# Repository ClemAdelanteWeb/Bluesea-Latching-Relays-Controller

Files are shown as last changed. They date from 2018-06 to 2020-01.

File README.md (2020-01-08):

### dernier update 2020-01-08
Modification du comportement de la détection du voltage minimum de la batterie suite à un problème pendant 2 mois d'absence.
Le SOC était toujours à 100% parce que le Victron ne détectait pas les petites consommations de courant (Victron BMV lui-même, contrôleur de batterie, conso du régulateur de panneau solaire). Le relai de charge ne s'est dont pas fermé et à mon retour la batterie était à 10.7v

J'ai aussi rajouté des détections de voltage trop haut ou trop bas pour chaque cellule. Respectueusement 2.8v et 3.8v.

### Gestion des relais de charge et décharge dans un système de batterie Lifepo4.

Dans un système avec batteries au lifepo4, il faut pouvoir couper la charge quand les batteries sont pleines, pour ne pas passer en mode float et abimer les batteries sur le long terme.

Toute décharge doit être rendue impossible si les batteries ont atteint leur maximum de capacité de décharge (en général 80%), tout en laissant la charge se faire.
Il faut donc deux relais qui permettent de bloquer la charge, bloquer la décharge et bloquer les deux ce qui ferait l'équivalent d'un coupe circuit.

Il existe plusieurs sortent de relais. Les classiques à solenoide qui sont finalement constitués d'une lamelle à ressort que vient plaquer et fermer une bobine qui une fois alimentée crée un champ magnétique. Cette bobine c'est une solénoide, qu'on retrouve dans tous les relais classiques.

Il est aisé de déduire que ce type de relai consomme de l'énergie en permanence pour que le contact se fasse et le courant puisse passer. Pour les meilleurs d'entre eux 0.1A 24/24h ce qui fait un total de 2.4Ah par jour et comme il en faut 2 on arrive à une consommation de 4.8Ah par jour.

Un relai classique consomme entre 0.3 et 1A, on arrive dans ce cas à des consommations non négligeables de 14Ah à 48Ah par jour, simplement pour alimenter des relais qui servent à :
- Celui de charge (Charge) : couper les différentes charges et ne pas laisser la batterie Lifepo4 en mode float
- Celui de décharge (Load) : isoler de toute décharge profonde la batterie Lifepo4 tout en laissant la possibilité de la charger.

Les relais à solénoide optimisés (0.1A) sont très chers et même 5Ah par jour étaient de trop pour moi. 

Il existe aussi des relais mosfet qu'on trouve partout en électronique de puissance. S'il est plus compliquer d'estimer leur consommation lorsqu'ils sont passant, on comprend vite qu'elle est élevée puisqu'il faut un radiateur pour dissiper la chaleur qu'il produit.
Les mosfets sont aussi évincés de ma liste.

Heureusement il reste une solution : les relais bi-stable (ou latching relay en anglais).
Ceux-ci possèdent deux solénoides par relai. Un pour ouvrir le contact et un autre pour le fermer. Cette fois ci, et au contraire des relais classique, la position de la lamelle est permanente. C'est à dire qu'il n'y a pas besoin d'alimenter en permanence le solénoide pour créer un champ magnétique et forcer à lamelle à rester en place. Ici, comme pour un interrupteur à deux positions le relai ne consomme du courant que pour changer son état.

C'est parfait sauf que ça complique les choses puisqu'il y a deux bobines à alimenter par relai. Et comment savoir dans quelle position est le relai, ouvert ou fermé ?

J'ai choisi d'utiliser les relais Blue Sea ML-RBS qui ne consomment aucun courant et ont aussi une sortie qui permet de connaitre l'état du relai (ouvert ou fermé). On peut récupérer cette information et la traiter avec l'Arduino.

Il faut au moins 2A en 12v pour ouvrir ou fermer le relai. L'arduino seul n'est pas capable de fournir une tel intensité ni un telle tension. J'utilise donc une cascade de transisteurs.

Le soucis majeur lors de la création de la carte a été que les relais sont cablés en High Side, c'est à dire que les solenoides se trouvent du côté positif du circuit ce qui implique d'utiliser une cascade de transistor pour les activer avec un système PNP + NPN.

Pour déterminer le SOC (capacité restante dans la batterie en pourcentage) et l'utiliser pour gérer mes relais, j'utilise mon controleur de batterie Victron BMV702 qui fournit cette information par son port de communication (VE Direct). 

J'ai ensuite pris le parti d'acquérir les tensions des 4 cellules que composent la batteries pour controller les écarts entre les cellules, vérifier si l'une d'entre elles venait à être sous-chargée ou sur-chargée et connaitre la tension totale de la batterie.

Autant d'informations capitales qui permettent aussi de controller les relais sans les données fournies par le Victron, si celui-ci venait à tomber en panne.

J'ai aussi ajouté un bouton ON/OFF pour désactiver l'utilisation du SOC venant du Victron.

L'arduino reçoit donc les informations suivantes : 
- Etat du relai de charge
- Etat du relai de décharge
- SOC via le controleur Victron
- Tension de chaque cellule
- Utilisation du Victron ON / OFF

Par la suite, je vais créer un petit écran pour afficher toutes les données (voltage des cellules, état des relais, cycle de charge ou cycle de décharge, sur-tension ou sous-tension détectée). 

Pour des batteries au lithium, il n'est pas recommandé de maintenir la charge à 100% (mode float).
Aujourd'hui le programme ne possède qu'un cycle de charge qui va de 95 à 100% du SOC. Un cycle se compose comme ceci : la batterie se charge jusqu'à 100%, puis la charge est bloquée jusqu'à ce que la batterie se vide de 5%. A 95% de SOC, donc, la charge est de nouveau autorisée. 

Pour prolonger la durée de vie des batteries lithium, le SOC idéal est entre 50 et 70%. Ce serait intéressant de pouvoir faire des cycles entre 50 et 70% lorsque l'on est au port par exemple et qu'on n'a pas besoin de toute la capacité de la batterie puisqu'elle est rechargée au quai. 
Une autre utilisation de ce cycle 50-70% pourrait être faite en hivernage, période pendant laquelle la batterie n'est pas solicitée mais que la charge peut être faite par un panneau solaire par exemple. Grâce au controleur il serait possible de laisser tourner un petit ventilateur 12V dans les endroits qui en auraient besoin, par exemple, en aillant la certitude qu'il ne déchargera pas la batterie en dessous de 50%.

Une fois que l'autonomie totale est requise on retourne sur le cycle normal qui est de 95 à 100%.

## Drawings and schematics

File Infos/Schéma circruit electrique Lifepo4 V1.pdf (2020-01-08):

@

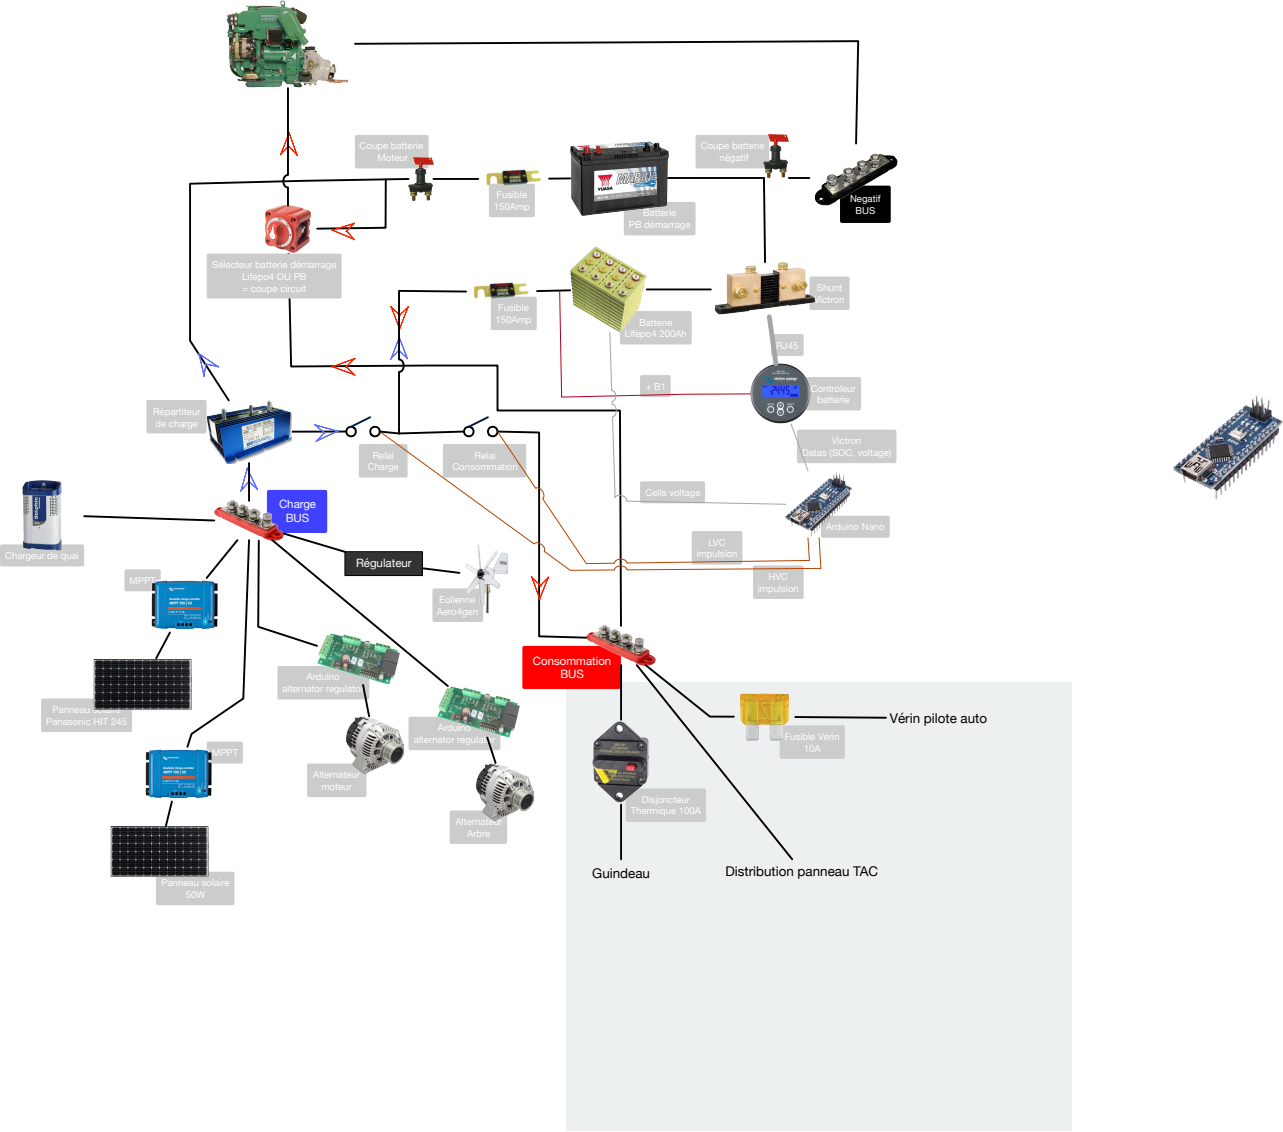
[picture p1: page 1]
Fusible Vérin 10A; Disjoncteur Thermique 100A; Coupe batterie négatif; Cells voltage; LVC impulsion; HVC impulsion; Arduino Nano; Controleur; batterie; Fusible 150Amp; Shunt Victron; Negatif BUS; Eolienne Aero4gen; Batterie PB démarrage; Batterie Lifepo4 200Ah; Arduino alternator regulator; Alternateur moteur; Alternateur Arbre; MPPT; Panneau solaire Panasonic HIT 245; Charge BUS; Consommation BUS; Répartiteur de charge; Relai Charge; Relai Consommation; Guindeau; Distribution panneau TAC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

Sélecteur batterie démarrage
Lifepo4 OU PB
= coupe circuit

Victron
Datas (SOC, voltage)

Chargeur de quai

Vérin pilote auto

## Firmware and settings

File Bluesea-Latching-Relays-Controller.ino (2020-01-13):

#include <AltSoftSerial.h>
#include <Thread.h>;
#include "BlueSeaLatchingRelay.h"
#include <Adafruit_ADS1015.h>
 
//------
// SETTINGS

const byte activatePrintStatus = 0;

// Checking cells differences
// var boolean
const byte activateCheckingCellsVoltageDifference = 1;

// Opening charge relay for SOC >= SOCMax
const int SOCMax = 1000;

// Re-Close Charge Relay when SOCMaxReset is reached
const int SOCMaxReset = 950;

// Opening Load relay if SOC <= SOCmin
const int SOCMin = 200;

// Re-Close Load Relay when SOCMaxReset is reached
const int SOCMinReset = 250;

// SOC Maximum time considerated valid 
// in mS
const int SOCMaxTimeValid = 10000;

// Maximum Voltage security
const int BatteryVoltageMax = 13800;  // 13,8v = 3,45v / Cell

// Waiting for Max Reset Voltage after reaching Max Voltage (time to discharge the battery enough to use it)
const int BatteryVoltageMaxReset = 13360;  

// Minimum Voltage security
const int BatteryVoltageMin = 12400; // 12,4v = 3,1v / Cell

// Waiting for Min Reset Voltage after reaching Min Voltage (time to re-charge the battery enough to use it)
const int BatteryVoltageMinReset = 12800; // 12,9  = 3,225v / Cell

// Minimum operating cell voltage
const int CellVoltageMin = 310;

// Maximum operating cell voltage
const int CellVoltageMax = 360;

// Voltage difference between cells  or batteries
// Absolute value (-100mV) = 100mV).
// in mV
const int CellsDifferenceMaxLimit = 150;

// Voltage difference maximum to considere that the battery bank can be starting using again
// in mV
const int CellsDifferenceMaxReset = 100; 


const byte LoadRelayClosePin = A2;
const byte LoadRelayOpenPin = A3;
const byte LoadRelayStatePin = A7;

const byte ChargeRelayClosePin = A0;
const byte ChargeRelayOpenPin = A1;
const byte ChargeRelayStatePin = A6;

const byte BuzzerPin = 7;

// if pin = 1, BMV infos are collected
const byte ActivateBmvSerialPin = 4;

// Number of cells in the battery
const int unsigned cellsNumber = 4;

// ADS1115 Calibration at 10v *1000
// Ex: 10 / 18107 = 0,000552273
// cell 1, 2, 3, 4 etc
float adc_calibration[] = {
  0.5518956,
  0.54827077,
  0.55232238,
  0.55189998
};

// END SETTINGS
//-------

// Program declarations

// RX pin 8 Tx pin 9
AltSoftSerial Bmv; 

// SoftwareSerial Bmv(BmvRxPin,BmvTxPin); // RX, TX
Thread RunApplication = Thread();

// ADS1115 on I2C0x48 adress
Adafruit_ADS1115 ads(0x48);

// Relays declaration
BlueSeaLatchingRelay LoadRelay;
BlueSeaLatchingRelay ChargeRelay;

unsigned int BatteryVoltage;
unsigned long BatteryVoltageUpdatedTime;

int CellsDifferenceMax;
unsigned long CellsDifferenceMaxUpdatedTime;

unsigned int SOC;
unsigned int SOCTemp;
unsigned int SOCCurrent;
unsigned long SOCUpdatedTime;

// If SOCDisSOCChargeCycling = true : the battery is full and Charge Relay is open 
bool SOCDisSOCChargeCycling = false;

// if SOCChargeCycling = true : the battery is empty and Load relay is opened
bool SOCChargeCycling = false;

// If High voltage has been detected (waiting for HighVoltageReset)
// Charge relay is closed
bool HighVoltageDetected = false;

// If Low voltage has been detected (waiting for LowVoltageReset)
// Load relay is closed
bool LowVoltageDetected = false;

// If a High voltage difference has been detected between cells
// waiting for a lower difference 
// Charge And Load relay are closed, Alarm is ON
bool CellsDifferenceDetected = false;

// If an individual cell voltage is too low
// waiting for a higher value
// force charging, alarm is ON
bool CellVoltageMinDetected = false;

// If an individual cell voltage is too high
// waiting for a lower value
// force discharging, alarm is ON
bool CellVoltageMaxDetected = false;


// victron checksum 
byte checksum = 0;
String V_buffer;
char c;

String MessageTemp;

int isfirstrun = 1;

void log(String message, byte buzz, byte buzzperiode = 100);


void setup()
{
  pinMode(LoadRelayClosePin, OUTPUT);
  pinMode(LoadRelayOpenPin, OUTPUT);
  pinMode(ChargeRelayClosePin, OUTPUT);
  pinMode(ChargeRelayOpenPin, OUTPUT);

  pinMode(ChargeRelayStatePin, INPUT_PULLUP);
  pinMode(LoadRelayStatePin, INPUT_PULLUP);

  pinMode(ActivateBmvSerialPin, INPUT);
  pinMode(BuzzerPin, OUTPUT);
  
  // Load Relay declaration
  LoadRelay.name = "Load relay";
  LoadRelay.openPin = LoadRelayOpenPin;
  LoadRelay.closePin = LoadRelayClosePin;
  LoadRelay.statePin = LoadRelayStatePin;

  // Charge Relay declaration
  ChargeRelay.name = "Charge relay";
  ChargeRelay.openPin = ChargeRelayOpenPin;
  ChargeRelay.closePin = ChargeRelayClosePin;
  ChargeRelay.statePin = ChargeRelayStatePin;
  
  Serial.begin(19200);
  Bmv.begin(19200); 

  RunApplication.onRun(run);
  RunApplication.setInterval(10000); // 10 sec

  ads.begin();

}
 
void loop() {
  if(isfirstrun) {
    bip(50);
    delay(50);
    bip(50);
    isfirstrun = 0;
  }
  
  if(isEnabledBMVSerialInfos()) {
    readBmvData();
  }

  if(RunApplication.shouldRun()) {
    RunApplication.run();
  }
  
}


/**
 * Checking Voltage AND SOC and close or open relays
 */
void run() {
  ChargeRelay.startCycle();
  LoadRelay.startCycle();

  
  // storing BatteryVoltage in temp variable
  int CurrentBatteryVoltage = getBatteryVoltage();

  // Get actual SOC
  SOCCurrent = getBatterySOC();

  
  // --- Normal LOAD routines
  // checking if Load relay should be closed
  
  // first general condition
  // Normal operating range voltage and relay open
  if((CurrentBatteryVoltage > BatteryVoltageMin) && (LoadRelay.getState() != LoadRelay.RELAY_CLOSE)) {
    
      // not in special event
      if((SOCChargeCycling == false)  && (LowVoltageDetected == false)) {

          // if using BMV SOC
          if(isUseBMVSerialInfos()){
            SOCCurrent = getBatterySOC();
            
            if((SOCCurrent > SOCMin)) {
              LoadRelay.setReadyToClose();        
              log(F("Load r. closing, routine"), 0);   
            }
            
          } 
          // Without SOC
          else {
            LoadRelay.setReadyToClose();        
            log(F("Load r. closing, routine"), 0);   
          }          
      }   
  }  


  // ---- Normal CHARGE routines
  // checking if Charge relay must be closed

  // first general condition
  if((CurrentBatteryVoltage < BatteryVoltageMax) && (ChargeRelay.getState() != ChargeRelay.RELAY_CLOSE)) {
    
      // not in special event
      if((SOCDisSOCChargeCycling == false) && (HighVoltageDetected == false)) {

          // if using BMV SOC
          if(isUseBMVSerialInfos()){
            SOCCurrent = getBatterySOC();
            
            if((SOCCurrent < SOCMax)) {
              ChargeRelay.setReadyToClose();        
              log(F("Charge r. closing, routine"), 0);   
            }
            
          } 
          // Without SOC
          else {
            ChargeRelay.setReadyToClose();        
            log(F("Charge r. closing, routine"), 0);   
          }          
      }   
  }
  

   
  //---
  // Cancelling Charge Cycling
  // 
  if(SOCChargeCycling == true) {
    
    if(isUseBMVSerialInfos()) {
           
        // if SOC > SOCMinReset
        if(SOCCurrent >= SOCMinReset) {
          SOCChargeCycling = false;
          LoadRelay.setReadyToClose();  

          MessageTemp = F("SOC min reset reached : current/min : ");
          MessageTemp += (String)SOCCurrent+" % /"+(String)SOCMinReset;       
          log(MessageTemp, 0);   
        }      
              
      } else {
          // Case IF Charge Cycling = true while it shouldn't
          // could append after disconnecting SOC check and SOCChargeCycling was ON.            
          // if Voltage battery high enough, we close the Load Relay
          
           if(LowVoltageDetected == false) {
            SOCChargeCycling = false;
            LoadRelay.setReadyToClose();
            log(F("Load r. closing, routine without SOC"), 0);   
          } 
      }
  }



  //---
  // Cancelling DisCharge Cycling
  // 
  if(SOCDisSOCChargeCycling == true) {
      if(isUseBMVSerialInfos()) {      
          // if SOC < SOCMaxReset
          if(SOCCurrent <= SOCMaxReset) {
            SOCDisSOCChargeCycling = false;
            ChargeRelay.setReadyToClose();  

            MessageTemp = F("SOC max reset reached : current/max : ");
            MessageTemp += (String)SOCCurrent+" % /"+(String)SOCMaxReset;       
            log(MessageTemp, 0);   
          }   
                   
      } else {
          // Case IF SOCDisSOCChargeCycling = true while it shouldn't
          // could append after disconnecting SOC check and SOCDisSOCChargeCycling was ON. 
          // if Voltage battery Low enough, we close the Charge Relay
          if(HighVoltageDetected == false) {
              SOCDisSOCChargeCycling = false;
              ChargeRelay.setReadyToClose();
              log(F("Charge r. closing, routine without SOC"), 0);   
           }     
      }    
  }
   
   
 // END NORMAL ROUTINES
 // -------------------------

  // if Charge relay has been manualy closed and doesn't match with the code
  // Relay must be opened
 if((SOCDisSOCChargeCycling == true) || (HighVoltageDetected  == true)) {
    if(ChargeRelay.getState() != ChargeRelay.RELAY_OPEN) {
      ChargeRelay.setReadyToOpen();
      log(F("Charge relay state doesn't match, relay opening"), 0);   
    }
 }

  // if Load relay has been manualy closed
  // Relay must be opened
  if((SOCChargeCycling == true) || (LowVoltageDetected  == true)) {
    if(LoadRelay.getState() != LoadRelay.RELAY_OPEN) {
      LoadRelay.setReadyToOpen();
      log(F("Load relay state doesn't match, relay opening"), 0);   
    }
 }



  // STARTING EXCEPTIONAL EVENTS
  if(isUseBMVSerialInfos()) {
  
      // SOC Max detection
      if((SOCCurrent >= SOCMax) && (SOCDisSOCChargeCycling == false)) {
        
        // Open Charge Relay
        SOCDisSOCChargeCycling = true;    
        ChargeRelay.setReadyToOpen();
        
        MessageTemp = F("SOC max reached : ");
        MessageTemp += (String) (SOCCurrent/10.0);
        MessageTemp += F(" %");  
        log(MessageTemp, 0);     
        
      }
  
  
       // SOC Min detection
      if((SOCCurrent <= SOCMin) && (SOCChargeCycling == false)) {
        
        // Open Load Relay
        SOCChargeCycling = true;
    
        LoadRelay.setReadyToOpen();

        MessageTemp = F("SOC min reached : current/min : ");
        MessageTemp += (String)SOCCurrent+" % / "+(String)SOCMin;   
        log(MessageTemp, 0);         
    } 
  } 
  


  //---
  // Voltage verifications
  if((millis() - BatteryVoltageUpdatedTime) < 6000) {

    // high voltage detection
     if((CurrentBatteryVoltage >= BatteryVoltageMax) && (HighVoltageDetected == false)) {
        // Open Charge Relay
        HighVoltageDetected = true;
        ChargeRelay.forceToOpen();
        MessageTemp = F("High v. detected : ");
        MessageTemp += (String) (CurrentBatteryVoltage/1000.0)+" V";
        log(MessageTemp, 0);
    } else {
      
      if(HighVoltageDetected == true) {

        if(ChargeRelay.getState() == ChargeRelay.RELAY_CLOSE) {       
          ChargeRelay.forceToOpen();  
          log(F("High Voltage Detected, force open"), 0);   
        }

        // if Voltage battery low enough, we close the Charge Relay
        if(CurrentBatteryVoltage <= BatteryVoltageMaxReset) {          
          HighVoltageDetected = false;
          ChargeRelay.setReadyToClose();  
          log(F("Voltage Max Reset reached, HighVoltageDetected > false"), 0);   
        }       
      }      
    }

    // Low voltage detection
    if((CurrentBatteryVoltage <= BatteryVoltageMin)  && (LowVoltageDetected == false)) {
       // Open LoadRelay
        LowVoltageDetected = true;
        LoadRelay.forceToOpen();
        log(F("Low Voltage Detected"), 0);   

        // Constrain battery to charge
        // in case of SOC >= max SOC, charge relay is open (can happen when very low consumption is not detected by Victron monitor)
        if(ChargeRelay.getState() == ChargeRelay.RELAY_OPEN) { 
            ChargeRelay.forceToClose();
            MessageTemp = F("Constrain Charge Relay to close. SOC : ");
            MessageTemp += (String) getBatterySOC();
            MessageTemp += F(" . Current voltage : "); 
            MessageTemp += (String) CurrentBatteryVoltage;
            log(MessageTemp, 0); 
        }

      
    } else {
      
      if(LowVoltageDetected == true) {

         if(LoadRelay.getState() == LoadRelay.RELAY_CLOSE) {       
          LoadRelay.forceToOpen();  
          log(F("Low Voltage Detected, force open"), 0);   
        }

         // Constrain battery to charge
        if(ChargeRelay.getState() == ChargeRelay.RELAY_OPEN) { 
            ChargeRelay.forceToClose();
            MessageTemp = F("Constrain Charge Relay to close. secound atempt.");
            log(MessageTemp, 0); 
        }

        
        // if Voltage battery high enough, we close the Load Relay
        if(CurrentBatteryVoltage >= BatteryVoltageMinReset) {
          LowVoltageDetected = false;
          LoadRelay.setReadyToClose();
          log(F("Voltage Min Reset reached, LowVoltageDetected > false"), 0);   
        }       
      }      
    }
    
  } else {
    MessageTemp = F("V. upd > 6s (");
    MessageTemp += (String) (BatteryVoltageUpdatedTime/1000);
    MessageTemp += F(" ms)");   
    log(MessageTemp, 1, 3000);

    LoadRelay.forceToOpen();
    log(F("No Voltage Detected, force open load relay"), 0);   
  }



  //---
  // Checking Cells / Batteries differences
  if(activateCheckingCellsVoltageDifference) {  
    CellsDifferenceMax = getMaxCellVoltageDifference();

    if((millis() - CellsDifferenceMaxUpdatedTime) < 10000) {
      
      // Too much voltage difference detected
       if((CellsDifferenceMax >= CellsDifferenceMaxLimit) && (CellsDifferenceDetected == false)) {
          // Open Load relay
          CellsDifferenceDetected = true;
          LoadRelay.forceToOpen();

          MessageTemp = F("Cells v. diff too high ");
          MessageTemp += (String) CellsDifferenceMax;
          MessageTemp += F(" Mv)");   
          log(MessageTemp, 1, 5000);
      } else {
        
        if(CellsDifferenceDetected == true) {
  
          // if Votage battery low enough, we close the LoadRelay
          if(CellsDifferenceMax <= CellsDifferenceMaxReset) {          
            CellsDifferenceDetected = false;
            LoadRelay.setReadyToClose();  
            
            log(F("Reset OK : Cells v. diff < Reset"), 0);
          }       
          
        }      
      }    
    } else {
      log(F("Cells diff upd > 10s"), 1, 2500);
    }

  }

// #########
   // checking for Individual cell voltage detection
   int i;
    int cellVoltage;
    for (i = (cellsNumber-1); i >= 0; i--) {
        if(i>0) {
           cellVoltage = getAdsCellVoltage(i) - getAdsCellVoltage((i-1));
        } else {
          cellVoltage = getAdsCellVoltage(i);
        }

        // HIGH individual voltage cell detected
        if((cellVoltage > CellVoltageMax) && (CellVoltageMaxDetected == false)) {
           // Open Charge Relay 
          CellVoltageMaxDetected = true;
          ChargeRelay.forceToOpen();
          
          // force discharging
          LoadRelay.forceToClose();
    
          MessageTemp = F("High individual voltage detected on cell ");
          MessageTemp += (String) (i);
          MessageTemp += F(" . Voltage : )");
          MessageTemp += (String) cellVoltage;  
          log(MessageTemp, 1, 2000);
          
        } else {    
          
          if(CellVoltageMaxDetected == true) {
      
            // if voltage cell low enough, we close the LoadRelay
            if(cellVoltage <= CellVoltageMax) {          
              CellVoltageMaxDetected = false; 
              log(F("Reset OK : high voltage cell low enough"), 0);
            }                   
          }      
        }


          // LOW individual voltage cell detected
        if((cellVoltage < CellVoltageMin) && (CellVoltageMinDetected == false)) {
           // Open load Relay, Close charge relay 
          CellVoltageMinDetected = true;
          LoadRelay.forceToOpen();

          // force charging
          ChargeRelay.forceToClose();
    
          MessageTemp = F("Low individual voltage detected on cell ");
          MessageTemp += (String) (i);
          MessageTemp += F(" . Voltage : )");
          MessageTemp += (String) cellVoltage;  
          log(MessageTemp, 1, 2000);
          
        } else {    
          
          if(CellVoltageMinDetected == true) {
      
            // if voltage cell high enough
            if(cellVoltage >= CellVoltageMin) {          
              CellVoltageMinDetected = false;        
              log(F("Reset OK : low voltage cell high enough"), 0);
            }          
          }      
        }  
    }

   

  // Serial.print("Cells voltage max difference : \t");
  // Serial.println(CellsDifferenceMax);
  // Serial.println('--');

  // applying actions on relays
  LoadRelay.applyReadyActions();
  ChargeRelay.applyReadyActions();
  
  if(activatePrintStatus) {
    printStatus();
  }
  // 
 // checkVoltages();
}



/**
 * Get Cell voltage from ADS1115
 * 
 */
int getAdsCellVoltage(unsigned int cellNumber) {

    int16_t adc;
    
    // waiting for correct values
    int unsigned attempts = 0;
    do {
      adc = ads.readADC_SingleEnded((uint8_t) cellNumber);
 
      if(attempts > 0) {
        Serial.println("Attemp : "+(String)+attempts+" / "+(String)+attempts);
      }
      
      attempts++;

      if(attempts >= 50) {
          MessageTemp = F("Cell ");
          MessageTemp += (String) cellNumber;
          MessageTemp += F(" attempts to get voltage > 50)");   
          log(MessageTemp, 1, 3000);
      }
      
    } while(adc <= 0 && attempts <= 50);

 // Serial.println("Cell "+(String)cellNumber+" : "+(String)adc+" : v "+(String) (adc * adc_calibration[cellNumber]));
 
  return adc * adc_calibration[cellNumber];
}

/**
 * Calculate max cell difference between all cells
 * Return value in mV
 */
float getMaxCellVoltageDifference() {
    float maxDiff = 0;

    // Cells voltages
    float cellsVoltage[(cellsNumber-1)];

    int i;
    int cellVoltage;
    for (i = (cellsNumber-1); i >= 0; i--) {
        if(i>0) {
           cellVoltage = getAdsCellVoltage(i) - getAdsCellVoltage((i-1));
        } else {
          cellVoltage = getAdsCellVoltage(i);
        }
       
        cellsVoltage[i] = cellVoltage;
    }

    CellsDifferenceMaxUpdatedTime = millis();

    return getDiffBtwMaxMin(cellsVoltage, (cellsNumber-1));
}


/**
 * Get Battery voltage
 * try with ADS1115 First, Victron BMV next
 */
int getBatteryVoltage() {
  int BatteryVoltageTemp = getAdsBatteryVoltage();
  
  if(BatteryVoltageTemp) {
    return BatteryVoltageTemp;
  }

  return 0;
}

/**
 * Return Battery Voltage (12v) via ADS 
 */
int getAdsBatteryVoltage() {
  int BatteryVoltageTemp = getAdsCellVoltage((cellsNumber-1));

  if(BatteryVoltageTemp > 100) {
      BatteryVoltageUpdatedTime = millis();
  } else {
    log(F("ADS C3 v. not available"),1, 5000);
  }
  
  return BatteryVoltageTemp;
}


/**
 * Return SOC value
 */
int getBatterySOC() {
  if((millis() - SOCUpdatedTime) < SOCMaxTimeValid) {
      return SOC;  
  } else {
      return 0;
  }
}


// Reading Victron Datas
// And extracting SOC and Voltage values
void readBmvData() {

  
  if (Bmv.available()) {
    c = Bmv.read();
    checksum += c;

    if (V_buffer.length() < 80) {
      V_buffer += c;
    }
      
    // end of line
    if (c == '\n') { 
    
      // Serial.println(V_buffer);
       if (V_buffer.startsWith("SOC")) {
        String temp_string = V_buffer.substring(V_buffer.indexOf("\t")+1);
        SOCTemp = temp_string.toInt();
       }
    
        // end of serie
      if (V_buffer.startsWith("Checksum")) {       
        
          byte result = checksum % 256;
    
          // checksum OK
         if(result == 0) {          
           SOC = SOCTemp;
           SOCUpdatedTime = millis();
         } else {
           // Checksum error
         }
    
          // begin new serie
         checksum = 0;
       }
    
      // begin new line
      V_buffer="";
    }     
  }
}


/**
 * Trigger Buzzer 
 */
void bip(int duration) {
    digitalWrite(BuzzerPin, HIGH); 
    delay(duration);    
    digitalWrite(BuzzerPin, LOW); 
}


/**
 * Return the value between Max and min values in an array
 */
float getDiffBtwMaxMin(float *values, int sizeOfArray) {
  float maxValue=0; 
  float minValue=0;
  float diffValue;
  
  for (byte k=0; k < sizeOfArray; k++) {
    if (values[k] > maxValue) {
       maxValue = values[k];  
    }
  }
  
  for (byte k=0; k < sizeOfArray; k++){
    if ((values[k] < minValue) || (minValue == 0)) {
       minValue = values[k];
    }
  }

  diffValue = (maxValue-minValue);
  
  return diffValue;
}

// Check if SOC Value is valid
boolean isSOCValid() {
   if((millis() - SOCUpdatedTime) < SOCMaxTimeValid) {
      return true;
   }

   return false;  
}

void log(String message, byte buzz, byte buzzperiode = 100) {
  // TODO
  // trigger alarm and led... 

  if(buzz) {
    bip(buzzperiode);
    delay(buzzperiode);
    bip(buzzperiode);
    delay(buzzperiode);
    bip(buzzperiode);
    delay(buzzperiode);
  
    Serial.print(F("ALARME : "));
  } else {
    Serial.print(F("ALERTE : "));
  }
 
  Serial.println(message);
  Serial.println(F("----"));
}
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

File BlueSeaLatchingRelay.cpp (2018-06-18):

/*
  Relay Library for controlling Latching Relays on a Marine or Home battery system.
  Created by Clément Lambert, 6th march 2018.
  Released into the public domain.
*/

#include "BlueSeaLatchingRelay.h"

/**
 * Constructor
 */
BlueSeaLatchingRelay::BlueSeaLatchingRelay() {
    
}

void BlueSeaLatchingRelay::setClosed() {
	this->isReadyToOpen = 0;

    if(this->getState() != BlueSeaLatchingRelay::RELAY_CLOSE) {
    
        analogWrite(this->closePin, 255);
        
        Serial.print(this->name);
        Serial.println(F(" closing"));
        
        delay(latchingDurationTime);
        
        analogWrite(this->closePin, 0);
        
        // delay to be sure that 2 relays can't be activated at the same time (causing fuse blow)
        delay(800);
             
        if(this->getState() == BlueSeaLatchingRelay::RELAY_CLOSE) {
        	Serial.println(F("R. closed"));
        } else {
        	Serial.println(F("Error, can't close r."));
        }
        
        this->state = BlueSeaLatchingRelay::RELAY_CLOSE;
    }
}


void BlueSeaLatchingRelay::setOpened() {
    
    if(this->getState() != BlueSeaLatchingRelay::RELAY_OPEN) {
    
        analogWrite(this->openPin, 255);
        
        Serial.print(this->name);
        Serial.println(F(" opening"));
        
        delay(latchingDurationTime);
        
        analogWrite(this->openPin, 0);
        
        // delay to be sure that 2 relays can't be activated at the same time (causing fuse blow)
        delay(800);
             
        if(this->getState() == BlueSeaLatchingRelay::RELAY_OPEN) {
        	Serial.println(F("r. opened"));
        } else {
        	Serial.println(F("Error, can't open r."));
        	// Serial.print("openPin : ");
        	// Serial.println(this->openPin);
        }
        
        this->state = BlueSeaLatchingRelay::RELAY_OPEN;
    }
}

void BlueSeaLatchingRelay::setReadyToClose() {
	this->isReadyToClose = 1;
}

void BlueSeaLatchingRelay::setReadyToOpen() {
	this->isReadyToOpen = 1;
}

void BlueSeaLatchingRelay::forceToClose() {
	this->isForceToClose = 1;
	this->setClosed();
}
void BlueSeaLatchingRelay::forceToOpen() {
	this->isForceToOpen = 1;
	this->setOpened();
}

/*
 * Apply ready actions at the end of cycle
 * ForceOpen or ForceClose have priority over readyToClose or readyToOpen
 * ForceOpen has also priority over ForceClose
 */
void BlueSeaLatchingRelay::applyReadyActions() {
	if((this->isForceToOpen != 1) && (this->isForceToClose != 1)) {
		if(this->isReadyToOpen == 1) {
			this->setOpened();
		} else if(this->isReadyToClose == 1){
			this->setClosed();
		}
	}
}

void BlueSeaLatchingRelay::startCycle() {
	this->isReadyToOpen = 0;
	this->isReadyToClose = 0;
	this->isForceToOpen = 0;
	this->isForceToClose = 0;
}

/*
* Getting relay state
* comparaison with the logic pin and the analogic state from BlueSea
* !! Relay value > 100 if relay open
*/
byte BlueSeaLatchingRelay::getState() {
	
	if(this->statePin) {
	 	int analogState = analogRead(this->statePin);
	 	if(analogState >= 100 && (this->state != BlueSeaLatchingRelay::RELAY_OPEN)) {
	 		this->state = BlueSeaLatchingRelay::RELAY_OPEN;
	 	}
	 	
	 	if(analogState < 100 && (this->state != BlueSeaLatchingRelay::RELAY_CLOSE)) {
	 		this->state = BlueSeaLatchingRelay::RELAY_CLOSE;
	 	}
	}
	
    return this->state;
}

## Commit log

2018-04-03 Deleting first fritzing schema
    [batterie-controleur-diagrame-cablage.fzz]
2018-05-29 Ameliorations and Cells voltages check
2018-06-17 Lot of improvements and checksum check from Victron VE DIRECT
    [batterie-controleur-diagrame-cablage-v3.fzz]
2020-01-08 More protection
    Checking for individual Min and Max cells voltages. Update min voltage detection behavior after BIG problem with Victron SOC not seeing very low current.
    [batterie-controleur-diagrame-cablage-v3.fzz]
